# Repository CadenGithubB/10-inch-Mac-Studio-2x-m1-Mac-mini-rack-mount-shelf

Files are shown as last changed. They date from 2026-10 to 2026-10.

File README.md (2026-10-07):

# 10" rack cradle: Mac Studio + 2× Mac mini

A 5U, 3D-printable cradle for a 10-inch rack. It holds one Mac Studio standing on its side and two Mac minis standing on edge beside it. The minis sit between movable separators, so the same frame works with M1 minis now and M4 minis later.

There are two ways to build it:

- **One piece.** The whole frame is a single print on a 256 × 256 × 256 mm printer (Bambu X1/P1/A1 class). It needs no screws and no supports.
- **Bolt-together.** Five smaller parts fit a 235 mm bed and are joined with 10 M3 screws.

Both builds use the same separators.

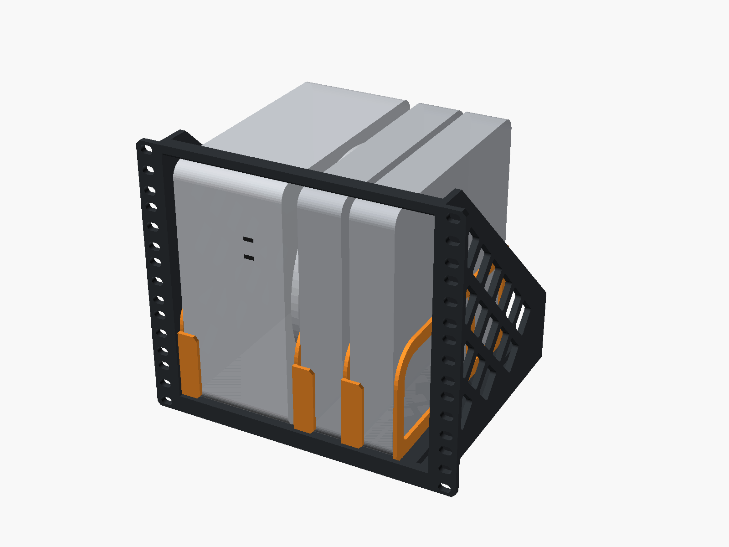
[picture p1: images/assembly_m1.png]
Mac Studio and two M1 minis in the cradle


| 2× M1 (now) | 2× M4 (later) | M1 + M4 |
|---|---|---|
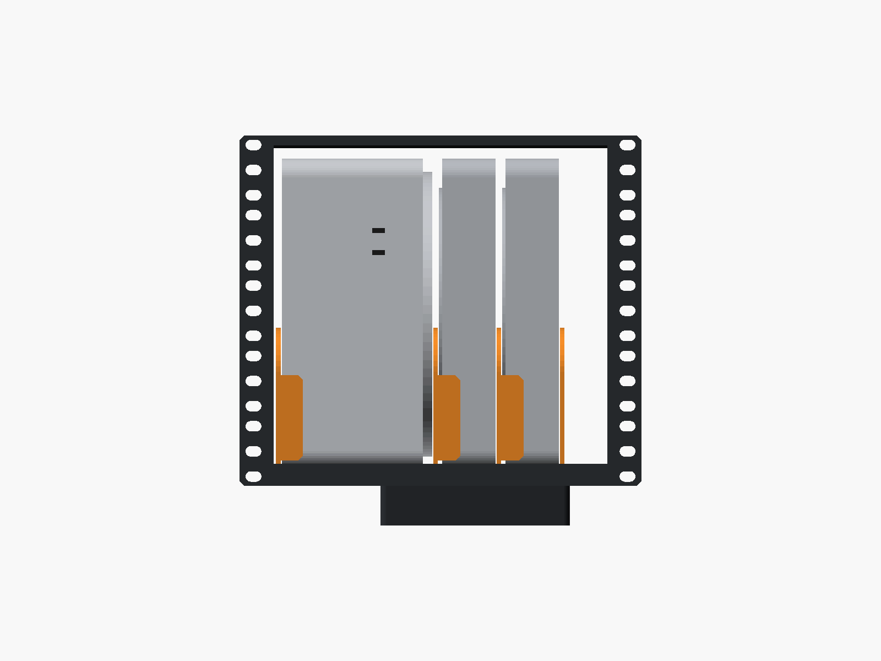
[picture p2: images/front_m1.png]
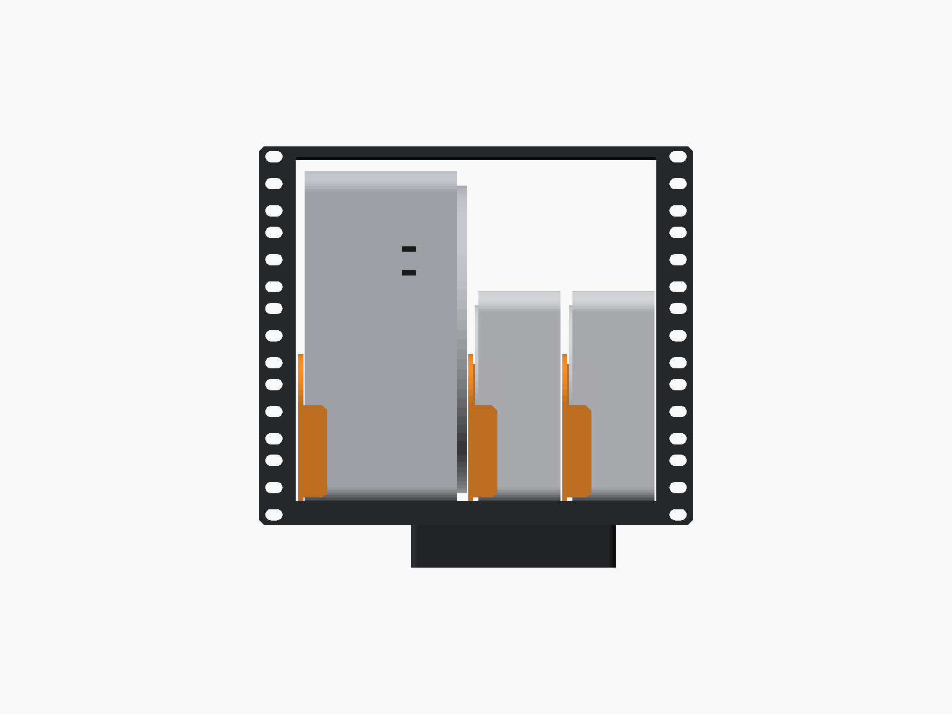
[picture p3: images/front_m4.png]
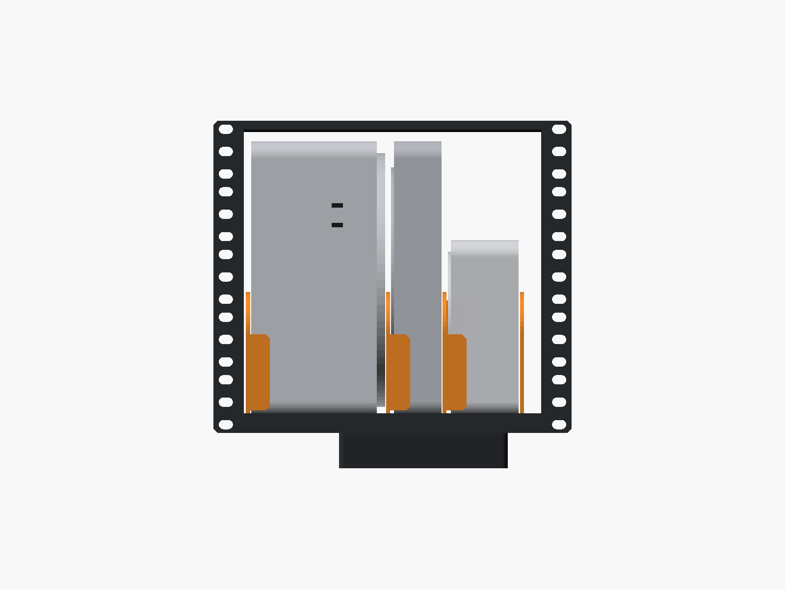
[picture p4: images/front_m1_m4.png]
|  |  |  |

## Why the Studio stands on its side

A 10" rack has 222.25 mm (8.75") between the rails. The Mac Studio and the M1 Mac mini are both 197 mm wide, so nothing fits beside a Studio lying flat.

On its side the Studio is 95 mm wide. That leaves about 110 mm next to it, which fits two minis on edge:

| Device | Footprint | On edge |
|---|---|---|
| Mac Studio | 197 × 197 × 95 mm | 95 mm wide, 197 mm tall |
| Mac mini M1 (2020) | 197 × 197 × 36 mm | 36 mm wide, 197 mm tall |
| Mac mini M4 (2024) | 127 × 127 × 50 mm | 50 mm wide, 127 mm tall |

The tallest device is 197 mm, so the cradle is 5U (222.25 mm).

The Studio's air intake is on its underside, so that face points **right**, toward the minis. Its foot holds the underside about 6 mm off the slot-2 separator. That leaves a gap down to the floor, right above the optional bottom fan (see below). Exhaust from all three Macs goes out the back, which is open. If you'd rather face the intake toward the open left side frame, set `studio_intake = "left"`. The bay is the same either way.

The floor between the two slot rows is a field of diamond vents, so air can rise into the bays from below. A solid band runs side to side across the middle of the vents. It stiffens the floor where it would otherwise sag most. The vents only help if the rack space under the cradle is open (an empty or vented U), not blocked by another device.

## Separators and doorstops

The floor has 6 separator slots. Count them from the left:

- **Slot 1** sits against the left side frame, on the Studio's left.
- **Slot 2** is the Studio's right-hand separator.
- **Slot 3** is where a separator goes after an M1.
- **Slot 4** is where a separator goes after an M4.
- **Slot 5** is where a separator goes after two M1s.
- **Slot 6** is where a separator goes after an M1 and an M4, in either order.

The slots go all the way through the 10 mm floor. Each separator drops 9.5 mm into one slot.

**Why only 6 slots:** the earlier version had a slot every 5 mm. That left walls only 1.6 mm thick between slots, held only at their ends and printed with the layer lines running across them. A firm sideways push on one separator (very roughly 4 kg) could crack one. With only the slots your layouts use, the thinnest wall is 11.6 mm. Strength grows with the square of thickness, so that's about 50× stronger, and the floor is much stiffer side to side. If you ever need other bay widths, set `slot_mode = "grid"` to get the 5 mm slots back. Treat those thin walls gently.

Every Mac has a separator on its left. Each separator has two **doorstops** on its right-hand side. They hook around the front and back edges of the Mac to their right, so that Mac can't slide out the front or back of the rack. They don't wrap all the way around.

- **Front doorstops** reach **14 mm** across the Mac's front. They cover only the edge closest to the separator, between 6 and 60 mm above the floor. The M4's front ports are in the middle of its 50 mm face, so they stay clear. With the Studio's underside facing right, its front ports end up on the right side of the face, away from its doorstop on the left. I couldn't measure exact port positions, so check against your Macs before printing.
- **Rear doorstops** reach 14 mm on the M4 separator. On the Studio/M1 separator they stay at **7 mm**, because the M1's rear ports run down the middle of its 36 mm back and an Ethernet or HDMI plug starts about 10 mm in. Change `rear_reach_studio_m1` if your plugs allow more.

The rear doorstop has to sit right behind the Mac it holds, and the separator after the last mini holds nothing. That gives three separator versions:

| File | Holds | Doorstops |
|---|---|---|
| [`stl/separator_studio_m1.stl`](stl/separator_studio_m1.stl) | the Studio or an M1 (197 mm deep) | front 14 mm; rear 7 mm at the back end |
| [`stl/separator_m4.stl`](stl/separator_m4.stl) | an M4 (127 mm deep) | front 14 mm; rear 14 mm, partway back and set high |
| [`stl/separator_end.stl`](stl/separator_end.stl) | nothing (it sits after the last mini) | none |

| Layout | Separators in slots | Bays (left → right) |
|---|---|---|
| Studio + 2× M1 | **1, 2, 3** Studio/M1, **5** end | Studio 96.4 · M1 37 · M1 37 · spare 27 mm |
| Studio + 2× M4 | **1** Studio/M1, **2, 4** M4 | Studio 96.4 · M4 52 · M4 52 mm (against the side frame) |
| Studio + M1 + M4 | **1, 2** Studio/M1, **3** M4, **6** end | Studio 96.4 · M1 37 · M4 52 · spare 12 mm |
| Studio + M4 + M1 | **1** Studio/M1, **2** M4, **4** Studio/M1, **6** end | Studio 96.4 · M4 52 · M1 37 · spare 12 mm |

Side-to-side play is 1.4 mm for the Studio, 1 mm for an M1 and 2 mm for an M4. Front-to-back play between the doorstops is 2.5 mm, which leaves room for ABS shrinking as it cools. For your M1 setup, print three Studio/M1 separators and one end separator. When you move to M4 minis, print two M4 separators.

The floor under the Studio has no slots, so it stays solid under the heaviest Mac. The spare bay in the M1 layout (about 27 mm) is wide enough for something thin, such as a USB hub or a slim SSD enclosure.

### Putting Macs in and taking them out

A separator can't slide past the Mac it holds, so you put Macs in from left to right:

1. Drop the slot-1 separator in.
2. Slide the Studio in about 1.5 cm to the right of its bay, then push it left so it tucks behind the doorstops.
3. Drop in the separator on the Studio's right.
4. Repeat for each mini.

To take Macs out, work from the right:

1. Lift out the separator on a Mac's right.
2. Slide the Mac about 1.5 cm right so it clears the doorstops on its left.
3. Pull the Mac out the front.

An M4 separator is easier, because its rear doorstop sits high: lift it about 85 mm, clear of the 127 mm-tall M4, and pull it out the front.

If you'd rather take any Mac out without touching the others, set `doorstop_rear = false` and re-export the separators. You then get front doorstops only. To remove a Mac, lift its left separator 10 mm, pull the separator out, then pull the Mac out. The 4 mm ramp at the back of the floor still stops a Mac from sliding off the back.

## Bottom fan (optional)

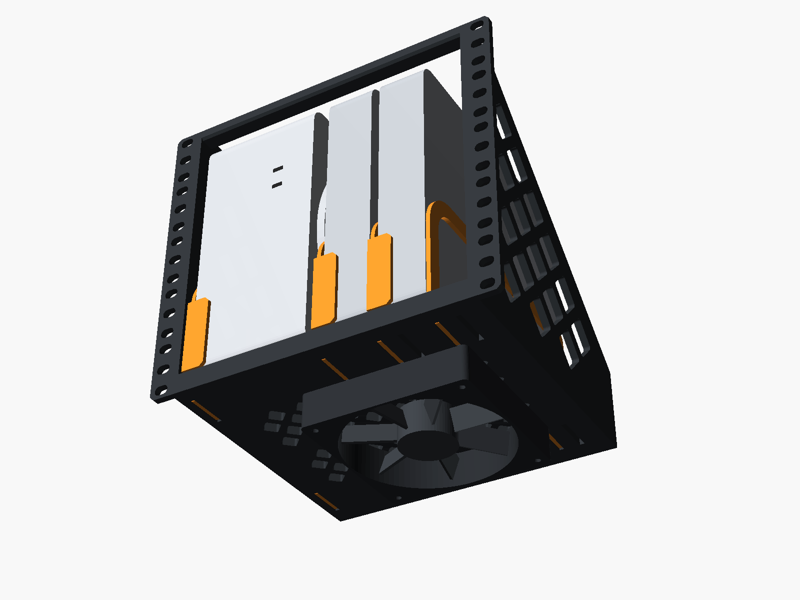
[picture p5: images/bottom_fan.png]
The cradle from below with a 120 mm fan


The floor has four countersunk holes for a standard **120 mm fan** (105 mm screw spacing). The fan mounts underneath and blows up through the floor vents. It's centred 25 mm right of the Studio's right-hand separator, so it sits mostly under the minis. The Studio's intake gap lies over the fan's blades rather than its dead center hub.

- **Hardware:** 4× M4 × 40 countersunk screws and 4× M4 nuts (nylon-insert nuts won't vibrate loose). They go down through the floor and the fan's corner holes. The heads sit flush with the floor. For a 15 mm slim fan, use M4 × 30. A standard 120 mm finger guard can go under the fan on the same screws.
- **Rack space:** the fan hangs 25 mm below the cradle, inside the 1U under it. Leave that U empty so the fan can pull air in.
- **Power:** a 5 V USB fan (for example a 5 V Noctua 120 mm) can run off a spare USB port on one of the Macs. A 12 V fan needs its own supply.
- **Where the air goes:** the Macs sit right on the floor, so they cover most of the vents under them. The air comes up through the gaps between them: the Studio's intake gap, the separator windows, and the space between the minis. Open floor where no Mac sits, such as the spare bay or behind the shorter M4s, is an easy escape route. If you want to push more air into the Macs, cover those vents with tape.

Set `fan_mount = false` to leave the holes out.

## Build A: one piece (256 mm printer)

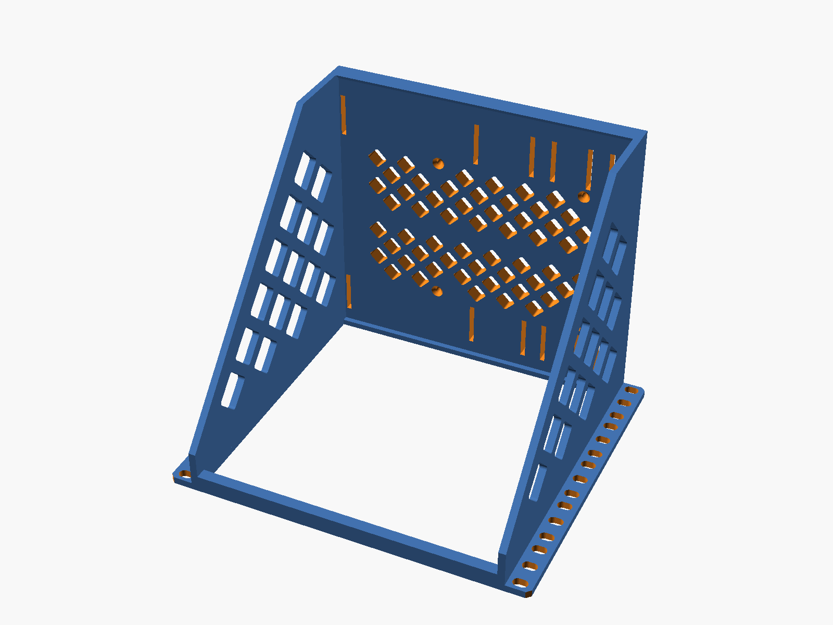
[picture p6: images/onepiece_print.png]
One-piece frame in print orientation


| File | Qty | Size (mm) |
|---|---|---|
| [`stl/frame_onepiece.stl`](stl/frame_onepiece.stl) | 1 | 254 × 221.5 × 206.5 |
| [`stl/separator_studio_m1.stl`](stl/separator_studio_m1.stl) | 3 for 2× M1 | 206 × 100 × 17 |
| [`stl/separator_m4.stl`](stl/separator_m4.stl) | 2 for 2× M4 (later) | 201 × 100 × 17 |
| [`stl/separator_end.stl`](stl/separator_end.stl) | 1 for 2× M1 | 198 × 100 × 3 |

The frame STL is already in print orientation: **face-down**, with the rack ears and the front edges on the bed. Printed this way:

- The top bar sits on the plate instead of bridging 210 mm in mid-air.
- The side-frame cutouts are 45° diamonds, and the rear stop is a 45° ramp.
- The floor vents are 45° diamonds as well.
- The widest bridge is 3.4 mm, at the tops of the separator slots.

It needs no supports.

The frame is 254 mm wide, which leaves about 1 mm on each side of a 256 mm plate. Center it, and don't add an outer brim. The part touches the bed only along a thin rectangular outline, so make sure the plate is clean. If you want more grip, use an inner-only brim or a little glue stick.

**Suggested settings:** 0.2 mm layers, 4 walls, 5 top/bottom layers, 15–20% gyroid infill. The frame is mostly thin walls, so walls add strength more than infill does. If you want more, go to 5–6 walls rather than 100% infill. The frame takes about 0.5 kg of filament. The separators print flat on their left face with the doorstops pointing up. They use 3 walls and need no supports.

**Material:** ABS, ASA or PETG. ABS and ASA hold their shape to about 95°C, compared with about 70°C for PETG. PLA can soften over time next to a warm Mac Studio.

**Printing in ABS or ASA:**

- Use an enclosed printer, such as an X1C or P1S, not an open A1. Let the chamber warm up for 10–15 minutes before starting, and keep the door closed.
- Set the bed to 100–110°C. Turn the part-cooling fan off for the first layers and keep it low (0–20%) after that.
- Stay at 15–20% infill. Solid ABS shrinks harder as it cools and is more likely to warp.
- The frame touches the bed along a thin outline, and its outer corners are the most likely to lift. Glue stick helps. There's no room for an outer brim on the left and right edges of a 256 mm plate, but an inner brim works. Give the separators a 3–5 mm brim.
- If the big frame keeps warping, the bolt-together version (Build B) prints as smaller, flatter parts that are much easier in ABS.
- Print somewhere ventilated, because ABS gives off fumes.

**Hardware:** only 4–6 rack screws, plus cage nuts if your rails need them. The ear slots are 6.6 × 10 mm, which fits M6, M5 and 10-32 screws and rail hole spacings from 235 to 237 mm. The optional bottom fan needs 4 M4 × 40 countersunk screws and nuts.

**Setup:**

1. Mount the frame in the rack with at least 2–3 screws per ear, including the top and bottom positions.
2. Load the separators and Macs left to right, as described under "Putting Macs in and taking them out". The Studio goes on its side with its underside facing right, toward the minis. Lift each Mac slightly to clear the 4 mm lip on the front edge. There is 6.4 mm of headroom under the top bar.

## Build B: bolt-together (235 mm bed)

| File | Qty | Size (mm) | Notes |
|---|---|---|---|
| [`stl/bolted/side_frame_left.stl`](stl/bolted/side_frame_left.stl) | 1 | 221 × 207 × 22 | Prints inner face down. The rack ear stands up. |
| [`stl/bolted/side_frame_right.stl`](stl/bolted/side_frame_right.stl) | 1 | 221 × 207 × 22 | Same as the left frame, mirrored. |
| [`stl/bolted/floor.stl`](stl/bolted/floor.stl) | 1 | 211 × 207 × 14 | Prints top face up. |
| [`stl/bolted/top_bar.stl`](stl/bolted/top_bar.stl) | 1 | 211 × 12 × 8 | Ties the frames together at the top front. |
| `stl/separator_*.stl` | per layout | up to 206 × 100 × 17 | Same separators as the one-piece build. |

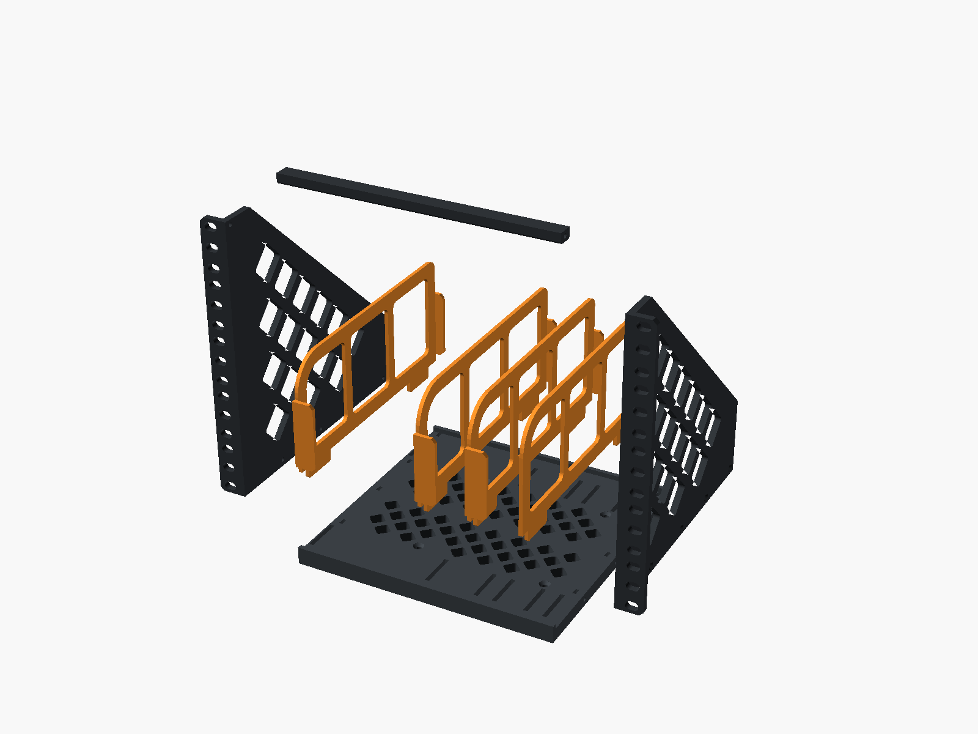
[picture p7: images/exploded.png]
Bolt-together parts


All parts are in print orientation and need no supports. The largest part is 222 × 211 mm. Any bed that is 235 × 235 mm or larger works. A 250 × 210 mm bed (Prusa MK4) also works if you turn the parts lengthwise.

**Suggested settings:** the same material and layer height as the one-piece build.

| Part | Walls | Infill |
|---|---|---|
| Side frames | 4 | 25% gyroid |
| Floor | 3 | 15–20% |
| Top bar | 4 | 40% |

**Hardware:**

- 10× M3 × 16 countersunk screws (DIN 7991 / ISO 10642)
- 10× M3 hex nuts
- 4–6 rack screws
- Optional bottom fan: 4× M4 × 40 countersunk screws and 4× M4 nuts

**Assembly:**

1. Drop an M3 nut into each of the 8 slots near the side edges of the floor. Slide one nut into each of the 2 slots in the back face of the top bar.
2. Hold a side frame against each side of the floor, with the ears at the front. Fasten each frame with 4 countersunk screws from the outside.
3. Fit the top bar between the top front corners of the frames, with one screw per side.
4. Then follow the setup steps for the one-piece build.

## Load

Everything hangs from the front rails: a Studio (2.7–3.6 kg) plus two M1 minis (1.2 kg each). The diamond lattice in each side frame carries that load back to the rack ears. If your rack has a shelf or a support point under the cradle, use it as well.

## Rack requirements

- 222.25 mm clear between the rails. The cradle body is 220.75 mm wide.
- About 207 mm of depth behind the front face of the ears, plus about 60 mm behind that for cables.
- 5U of vertical space.

## Customizing

Everything is in [`mac_rack_shelf.scad`](mac_rack_shelf.scad) (OpenSCAD 2021.01 or newer). Open it in OpenSCAD and use the Customizer, or set values on the command line. Useful parameters:

| Parameter | Default | What it does |
|---|---|---|
| `part` | `assembly` | What to render: `assembly`, `frame_onepiece`, `separator_studio_m1`, `separator_m4`, or a bolted part |
| `build` | `onepiece` | Frame used in the assembly preview: `onepiece` or `bolted` |
| `config` | `m1` | Preset used in the assembly preview: `m1`, `m4`, `m1_m4`, `m4_m1` |
| `rack_opening` | 222.25 | Clear width between your rack's rails |
| `rail_hole_pitch` | 236.5 | Centre-to-centre of the rail holes |
| `slot_w` / `tab_clear` | 3.4 / 0.3 | Separator fit. Raise `slot_w` if the tabs are too tight on your printer. |
| `floor_vents` | `true` | Diamond vents in the floor between the slot rows |
| `vent_spine` | 10 | Width of the solid band across the middle of the vents (0 removes it) |
| `slot_mode` | `presets` | `presets`: the 6 slots the layouts use. `grid`: a slot every 5 mm (thinner walls). |
| `doorstop_rear` | `true` | Set to `false` for front doorstops only, so any Mac slides out on its own |
| `doorstop_reach` | 14 | How far the front doorstops (and the M4 rear one) hook across a Mac |
| `fan_mount` | `true` | Screw holes for a 120 mm fan under the floor |
| `fan_offset_x` | 25 | Fan centre, in mm right of the Studio's right-hand separator |
| `studio_intake` | `right` | Which way the Studio's underside (air intake) faces |
| `rear_reach_studio_m1` | 7 | How far the Studio/M1 rear doorstop hooks across the back. It's kept short to clear the M1's rear plugs. |
| `studio_play` | 1.4 | Side-to-side play in the Studio bay. This also sets where slot 1 sits. |
| `vent_pitch` / `vent_strut` | 22 / 5 | Vent size and rib width |
| `sep_h` | 90 | Separator height above the floor |
| `studio_dim`, `m1_dim`, `m4_dim` | Apple specs | Device sizes used for the preview |

To regenerate the STLs and images, run `./build.sh`. On a headless machine, run `xvfb-run -a ./build.sh`.

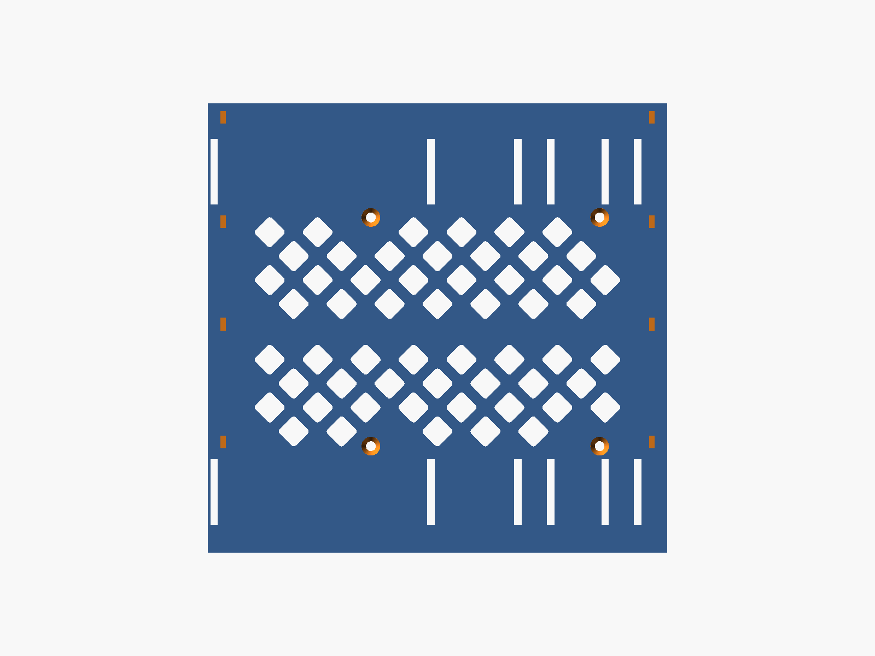
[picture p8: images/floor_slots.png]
Floor with separator slots and vents


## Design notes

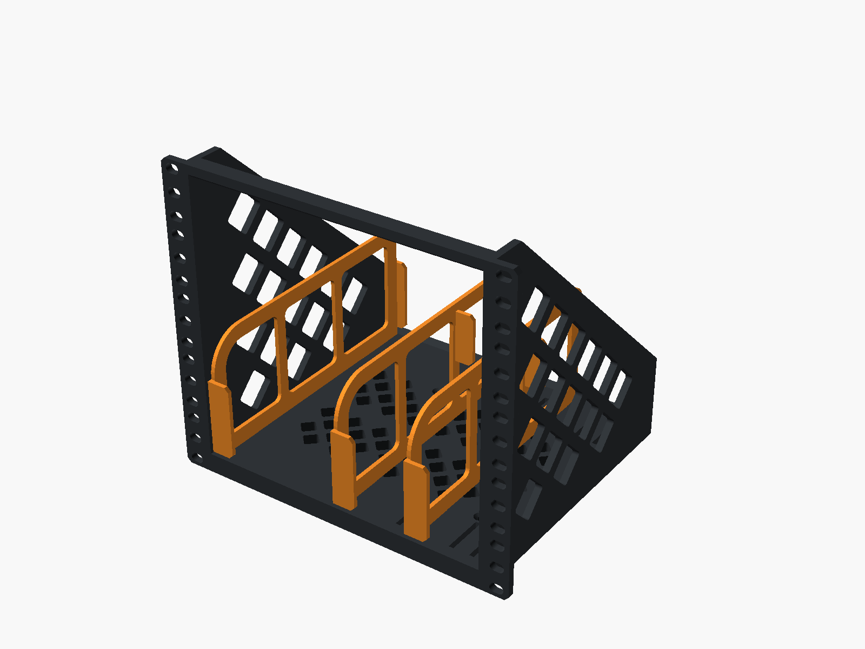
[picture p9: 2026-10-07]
images/separators_m4.png

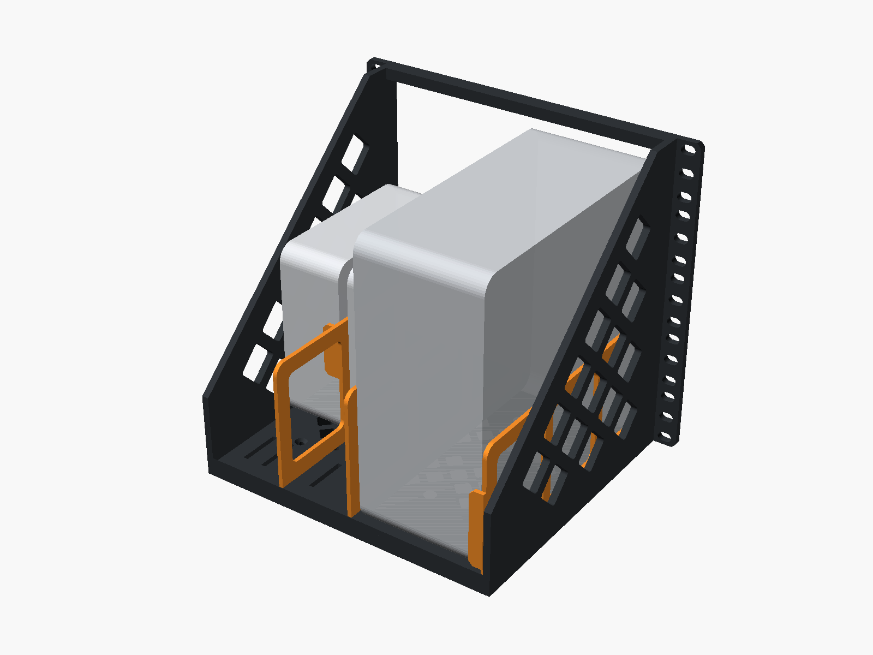
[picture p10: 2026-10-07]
images/rear_m4.png

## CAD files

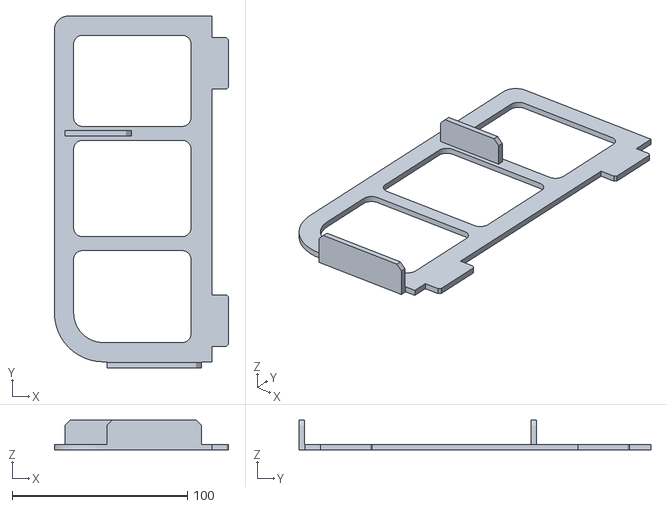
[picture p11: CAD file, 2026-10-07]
stl/separator_m4.stl
99.5 x 201.0 x 17.0

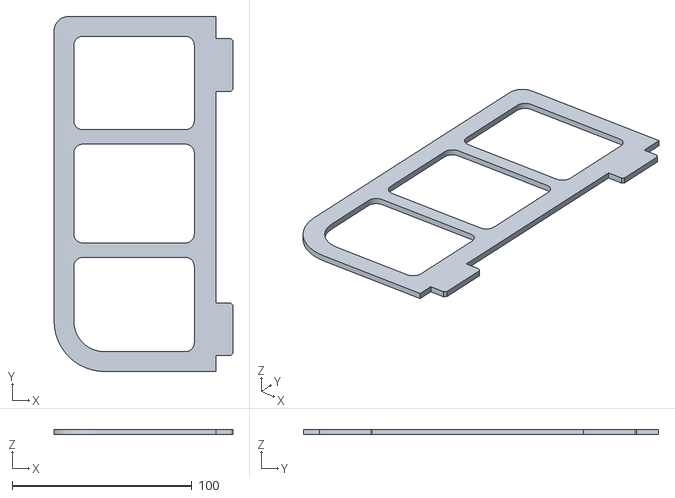
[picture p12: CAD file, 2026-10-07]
stl/separator_end.stl
99.5 x 197.5 x 3.00

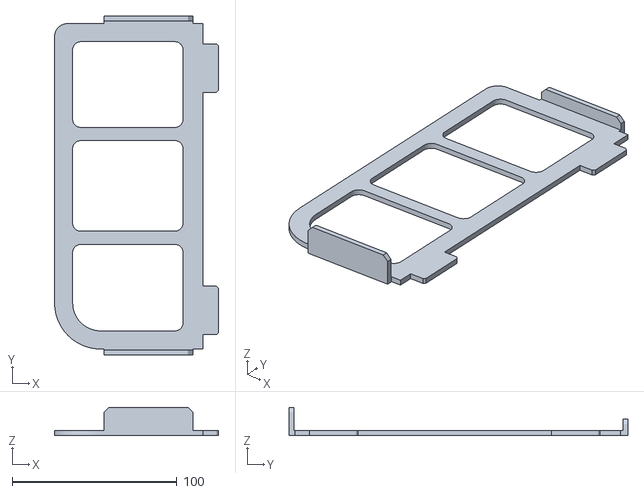
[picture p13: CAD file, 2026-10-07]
stl/separator_studio_m1.stl
99.5 x 205.5 x 17.0

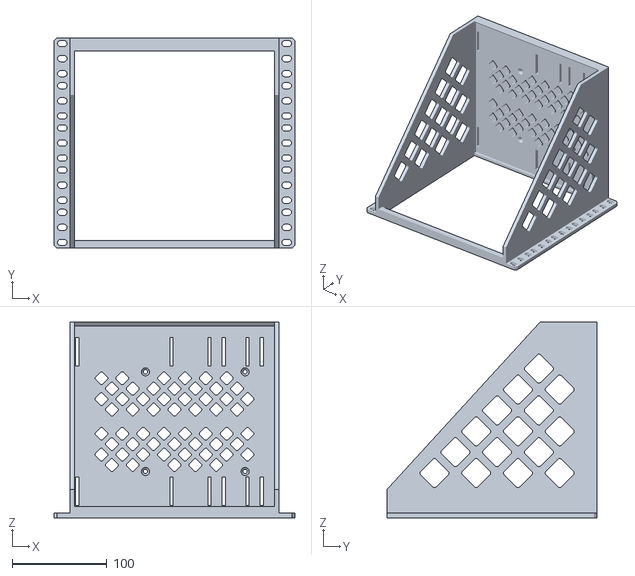
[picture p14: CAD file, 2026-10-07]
stl/frame_onepiece.stl
254.0 x 221.4 x 206.5

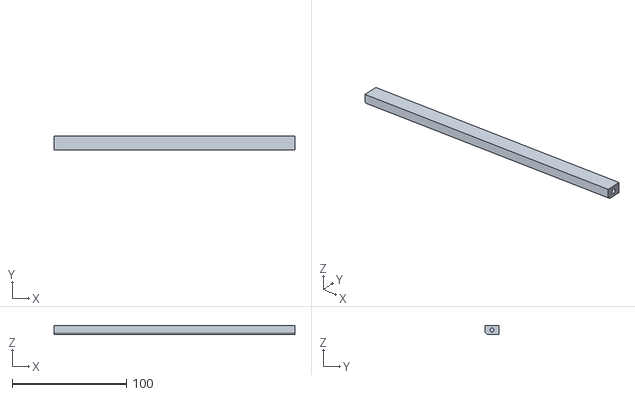
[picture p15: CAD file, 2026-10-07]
stl/top_bar.stl
210.8 x 12.0 x 8.00

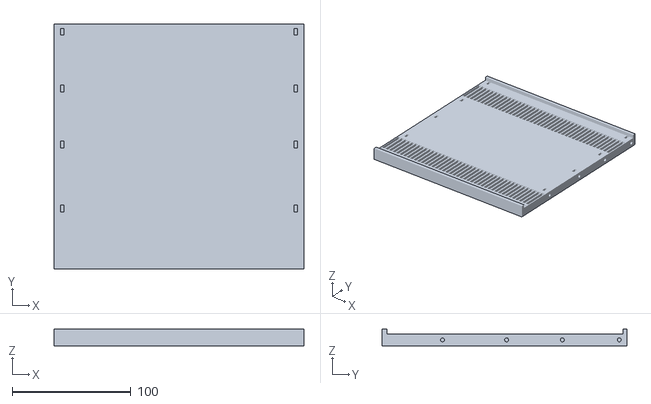
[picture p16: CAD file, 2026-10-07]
stl/floor.stl
210.8 x 206.5 x 14.0

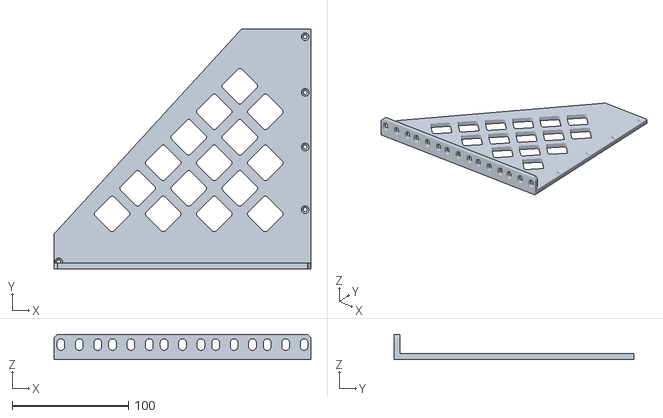
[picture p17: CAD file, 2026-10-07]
stl/bolted/side_frame_right.stl
221.4 x 206.5 x 21.6

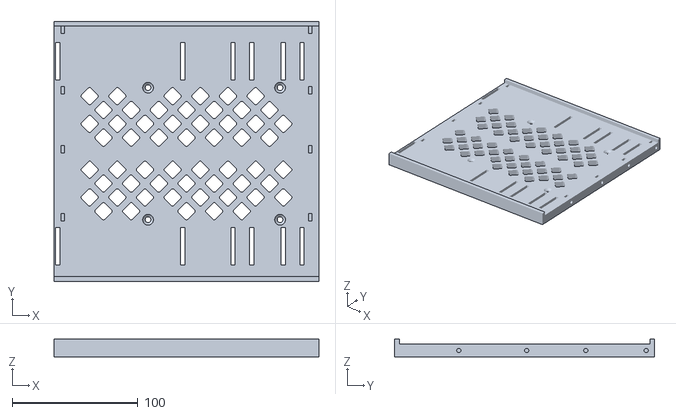
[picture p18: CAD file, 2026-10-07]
stl/bolted/floor.stl
210.8 x 206.5 x 14.0

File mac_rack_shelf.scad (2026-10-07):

// =====================================================================
//  10" rack cradle: 1x Mac Studio + 2x Mac mini (M1 now, M4 later)
//  5U, open front, 3D-printable. Two ways to build it:
//    * one piece  - the whole frame in a single print, face-down on a
//                   256 x 256 mm bed, no supports, no screws
//    * bolted     - five smaller parts joined with M3 screws (235 mm bed)
//
//  Layout (front view):
//
//      |<-------------- 210.75 mm between side plates -------------->|
//      | |  Mac Studio    | |  mini  | |  mini  | |   spare / gap    |
//      |S|  on its side   |S|        |S|        |S|                  |
//      | |  (96.4 mm bay) | |        | |        | |                  |
//      +=+================+=+========+=+========+=+==================+
//       1                 2        3   4     5    6     (separator slots)
//
//  Separators drop into numbered slots, so the same frame takes
//  M1 minis (36 mm thick), M4 minis (50 mm), or a mix. Every Mac has a
//  separator on its left, and each separator has small doorstops on its
//  right-hand side that hook around the front (and back) edge of that Mac.
//
//  Coordinates (assembled):  X = left/right (0 = rack centre),
//  Y = depth (0 = back face of the rack ears, + towards the rear),
//  Z = up (0 = bottom of the frame).
//
//  Render one part:   openscad -D 'part="frame_onepiece"' -o frame.stl mac_rack_shelf.scad
//  The floor can take an optional 120 mm fan underneath (fan_mount).
//
//  Parts: assembly | frame_onepiece | separator_studio_m1 | separator_m4 | separator_end
//         side_frame_left | side_frame_right | floor | top_bar   (bolted build)
// =====================================================================

/* [View] */
part   = "assembly";  // [assembly, frame_onepiece, separator_studio_m1, separator_m4, separator_end, side_frame_left, side_frame_right, floor, top_bar]
// Frame shown in the assembly preview
build  = "onepiece";  // [onepiece, bolted]
// Preset separator layout used by the assembly preview
config = "m1";        // [m1, m4, m1_m4, m4_m1, studio_only]
show_devices = true;
show_fan     = true;   // draw the optional bottom fan in the preview
explode = 0;          // [0:5:60] pulls the bolted parts apart

/* [Rack] */
U              = 44.45;
rack_units     = 5;
panel_w        = 254;     // 10" panel width
rack_opening   = 222.25;  // clear width between the rails (8.75")
rail_hole_pitch = 236.5;  // centre-to-centre of rail holes (racks vary 235-237)
side_clear     = 0.75;    // gap between side plate and rail, per side
ear_slot_d     = 6.6;     // fits M6 / M5 / 10-32 rack screws
ear_slot_len   = 10;      // horizontal slot, absorbs 235-237 mm hole pitch

/* [Devices] */
studio_dim = [197, 197, 95];   // W, D, H lying flat (Apple spec)
m1_dim     = [197, 197, 36];
m4_dim     = [127, 127, 50];

/* [Frame] */
side_t      = 5;     // side plate thickness
ear_t       = 5;     // rack ear thickness
depth       = 201.5; // frame depth behind the ears
h_rear      = 60;    // side-frame height at the rear
col_d       = 25;    // full-height solid column behind the ear
frame_border = 12;   // width of the outer frame members
bottom_band = 22;    // solid band along the floor joint
lat_pitch   = 44;    // diamond lattice: centre spacing
lat_strut   = 8;     // diamond lattice: strut width (45 deg, prints face-down or flat)
onepiece_overlap = 0.5;  // floor/top bar sink this far into the side plates

/* [Floor] */
floor_t     = 10;
lip_h       = 4;    // front lip that stops devices sliding out
lip_t       = 4;
rear_lip_h  = 4;
rear_lip_t  = 3.5;  // bolted floor only; the one-piece floor uses a 45 deg ramp

/* [Separator slots] */
// presets: only the 6 slots the M1/M4 layouts use (thick floor between them)
// grid:    a slot every slot_pitch mm, for odd-sized devices (1.6 mm walls between slots)
slot_mode   = "presets";   // [presets, grid]
slot_pitch  = 5;
slot_w      = 3.4;
m1_play     = 1;     // side-to-side play in an M1 bay (37 mm bay)
m4_play     = 2;     // side-to-side play in an M4 bay (52 mm bay)
slot_rows   = [[8, 38], [155, 185]];   // Y ranges of the two slot rows (cut through the floor)
studio_play = 1.4;   // side-to-side play in the Studio bay; sets where slot 2 sits
slot_wall   = 1.2;   // floor left between slot 1 and the left side plate

/* [Floor vents] */
floor_vents      = true;
vent_pitch       = 22;   // diamond centre spacing
vent_strut       = 5;    // rib width between diamonds (45 deg, prints without supports)
vent_side_margin = 16;   // solid floor kept along each side plate
vent_row_margin  = 5;    // solid floor kept next to each slot row
vent_spine       = 10;   // solid left-to-right band across the middle of the vents (0 = none)

/* [Separators] */
sep_t       = 3;
sep_h       = 90;    // height above the floor
tab_clear   = 0.3;   // per end, along Y
tab_depth   = 9.5;   // tabs reach 0.5 mm short of the floor's underside

/* [Doorstops] */
// Each separator holds the Mac on its right: a doorstop in front of it and
// one behind it. They print flat with the separator, pointing up. The
// separator after the last mini holds nothing and has no doorstops.
doorstop_reach = 14;         // how far the front doorstops (and the M4 rear one) reach across the Mac
rear_reach_studio_m1 = 7;    // Studio/M1 rear doorstop: kept short to clear the M1's rear plugs
doorstop_t     = 3;          // doorstop thickness, front to back
doorstop_z     = [16, 70];   // height of the front doorstop and the Studio/M1 rear one
m4_rear_z      = [56, 94];   // the M4 rear doorstop sits high so the separator lifts out over an M4
doorstop_rear  = true;       // false: front doorstops only, so any Mac slides out on its own
dev_front      = -1;         // front face of the Macs (back of the floor's front lip)
dev_play_y     = 2.5;        // front-to-back play between the doorstops (leaves room for ABS shrinking ~0.5%)

/* [Bottom fan] */
// Optional 120 mm fan screwed under the floor, blowing up through the vents.
// M4 countersunk bolts go down through the floor and the fan's corner holes,
// with nuts underneath; the heads sit flush with the floor.
fan_mount      = true;
fan_size       = 120;
fan_thick      = 25;     // preview only; a 25 mm fan fits in the 1U below the cradle
fan_hole_pitch = 105;    // standard 120 mm fan screw spacing
fan_hole_d     = 4.5;    // M4 clearance (fan corner holes are about 4.3-4.5 mm)
fan_csk_d      = 8.6;    // M4 countersunk head
fan_offset_x   = 25;     // fan centre, right of the Studio's right-hand separator
studio_intake  = "right"; // [right, left] which way the Studio's underside (its air intake) faces

/* [Top bar] */
bar_h       = 8;
bar_d       = 12;

/* [Hardware: M3 countersunk + hex nut] */
bolt_d      = 3.4;
csk_d       = 6.6;
nut_af      = 5.5;   // across flats
nut_t       = 2.4;
nut_clear   = 0.3;
floor_bolt_y = [46, 100, 147, 195];
floor_bolt_z = 5;
nut_inset   = 7;     // nut centre distance from the floor/bar end face

$fn = 48;
eps = 0.01;

// ---------------------------------------------------------------------
// Derived dimensions
// ---------------------------------------------------------------------
panel_h  = rack_units * U - 0.8;            // 221.45 for 5U
frame_w  = rack_opening - 2 * side_clear;   // outside of side plates
inner_w  = frame_w - 2 * side_t;            // between side plates
xi       = inner_w / 2;                      // inner face of right plate
xo       = frame_w / 2;                      // outer face of right plate
y_front  = -ear_t;
y_back   = depth;
bar_bolt_y = y_front + bar_d / 2;
bar_bolt_z = panel_h - bar_h / 2;

// Slot 1 sits against the left side plate, on the Studio's left. Slot 2 is
// the Studio's right-hand separator. The rest sit where a separator lands
// after one or two minis (M1 or M4), unless its doorstops would hit the
// right side plate. The floor under the Studio has no slots.
slot_x1 = -xi + slot_w / 2 + slot_wall;
slot_x0 = slot_x1 + sep_t + studio_dim[2] + studio_play;
fan_c   = [slot_x0 + fan_offset_x, (slot_rows[0][1] + slot_rows[1][0]) / 2];
fan_holes = [for (sx = [-1, 1], sy = [-1, 1]) fan_c + [sx, sy] * fan_hole_pitch / 2];

function bay_w(kind) = kind == "m4" ? m4_dim[2] + m4_play : m1_dim[2] + m1_play;
// a separator after the last mini has no doorstops, so it only needs to clear the side plate
function slot_fits(x) = x + sep_t / 2 + 0.5 <= xi;
// Separator positions from the Studio's right-hand separator onward, for a
// list of minis left to right. The last one is left out when the final
// mini simply sits against the side plate.
function mini_xs(devs, i = 0, x = slot_x0) =
    i < len(devs)
        ? concat([x], mini_xs(devs, i + 1, x + sep_t + bay_w(devs[i])))
        : (slot_fits(x) ? [x] : []);
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

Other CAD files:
stl/bolted/side_frame_left.stl
stl/bolted/top_bar.stl

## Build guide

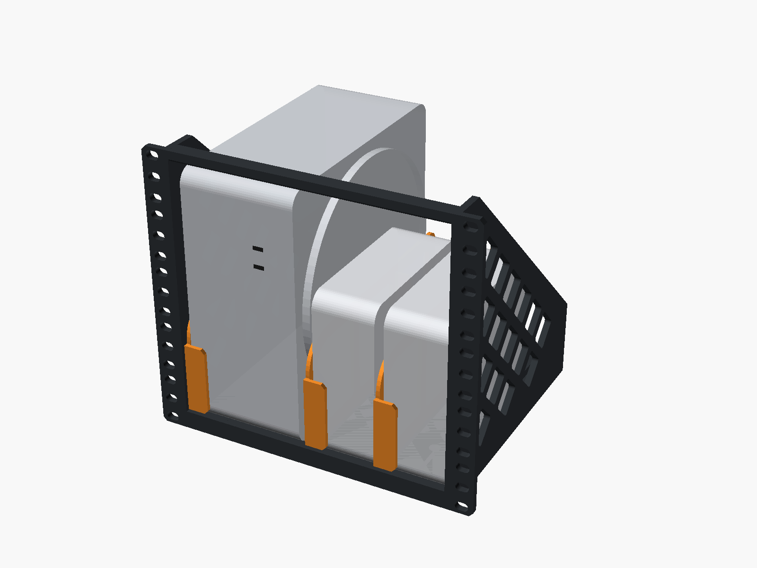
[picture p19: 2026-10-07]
images/assembly_m4.png

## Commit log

2026-10-07 Add 5U 10" rack cradle for Mac Studio + 2 Mac minis
    Parametric OpenSCAD model of a bolt-together, 3D-printable cradle:
    the Mac Studio stands on its side, and two Mac minis stand on edge in
    bays set by drop-in separators. The floor has 42 numbered slots at a
    5 mm pitch, so the same frame takes M1 minis (36 mm) now and M4 minis
    (50 mm) later.
    Includes print-oriented STLs, preview renders, a build script and a
    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
    [floor.stl, mac_rack_shelf.scad, separator.stl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]
2026-10-07 Add one-piece frame that prints face-down on a 256 mm bed
    The side frames, floor and top bar can now be fused into a single
    part (frame_onepiece) with no screws. It prints face-down, with the
    rack ears on the bed, inside 254 x 221.5 x 206.5 mm. In that
    orientation the top bar sits on the plate instead of bridging 210 mm.
    To keep it support-free, the side-frame cutouts are now a 45 degree
    diamond lattice (whole diamonds only, so no flat ceilings), and the
    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
    [floor.stl, frame_onepiece.stl, mac_rack_shelf.scad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]
2026-10-07 Cut separator slots through the floor and add floor vents
    The separator slots now go all the way through the 10 mm floor, and
    the separator tabs are 9.5 mm deep (up from 4.7 mm), so each separator
    sits about twice as deep and stands up more firmly.
    The floor between the two slot rows gets a field of 45 degree diamond
    vents so air can rise into the bays from below. Solid margins stay
    along the side plates and next to each slot row. Because every vent
    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
    [floor.stl, frame_onepiece.stl, mac_rack_shelf.scad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]
2026-10-07 Halve the separator slots and add a solid band across the vents
    Separator slots now exist only beside the Studio: 23 slots at a 5 mm
    pitch, renumbered so slot 1 is always the Studio's separator. Taking
    every other slot instead would have left the M4 bays at 47 or 57 mm.
    Dropping the slots under the Studio keeps every layout exact and
    leaves the floor solid under the heaviest Mac. The mirrored layout
    with the Studio on the right is no longer supported.
    New presets: 2x M1 = 1, 9, 17; 2x M4 = 1, 12, 23; M1 + M4 = 1, 9, 20;
    M4 + M1 = 1, 12, 20.
    The floor vents are split into two fields by a solid band that runs
    from side plate to side plate across the middle (vent_spine, 10 mm).
    It stiffens th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
    [floor.stl, frame_onepiece.stl, mac_rack_shelf.scad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]
2026-10-07 Add a slot left of the Studio and doorstops on the separators
    A new slot 1 sits against the left side plate, so the Studio now has a
    separator on both sides. Everything to its right moves over 4.4 mm.
    Slots are now 1-21: slot 2 is the Studio's right-hand separator, and
    slots 2-21 run 5 mm apart.
    Every Mac now has a separator on its left. That separator carries two
    doorstops on its right face, which hook 7 mm around the Mac's front and
    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
    [floor.stl, frame_onepiece.stl, mac_rack_shelf.scad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]
2026-10-07 Cut only the six slots the layouts use and drop the slot numbers
    The 5 mm slot grid left walls only 1.6 mm thick between slots. Those
    walls were held only at their ends (the slots go through the floor) and
    loaded across their layer lines in the face-down print. A firm sideways
    push on one separator could crack one, and the two slot rows made the
    floor weak side to side.
    By default the floor now has only the separator positions the M1/M4
    layouts use. They are computed from the bay widths: left of the Studio,
    right of the Studio, after one M1, after one M4, after two M1s, and
    after an M1 plus an M4. The thinnest wall between slots goes from
    1.6 mm to 11.6 mm. slot_mode = "grid" brings back a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
    [floor.stl, frame_onepiece.stl, mac_rack_shelf.scad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]
2026-10-07 Double the front doorstops and add an end separator
    The front doorstops now reach 14 mm across each Mac (was 7 mm), and so
    does the M4 separator's rear doorstop. The Studio/M1 rear doorstop stays
    at 7 mm (rear_reach_studio_m1): the M1's rear ports run down the middle
    of its 36 mm back, and a longer stop could foul an Ethernet or HDMI plug.
    With 14 mm doorstops, a separator in slot 6 would hit the side plate.
    That separator holds nothing anyway, so the separator after the last
    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
    [floor.stl, frame_onepiece.stl, mac_rack_shelf.scad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]
2026-10-07 Add a 120 mm fan mount under the floor and turn the Studio's intake inward
    The floor gets four countersunk M4 holes on the standard 105 mm
    pattern for a 120 mm fan that mounts underneath and blows up through
    the vents. Vents near the screws are skipped, so the floor stays solid
    around each hole. The fan is centred 25 mm right of the Studio's
    right-hand separator (fan_offset_x), so it sits mostly under the minis
    with the Studio's intake gap over its blades. fan_mount = false leaves
    the holes out.
    The Studio now faces its underside (air intake) right, toward the
    minis (studio_intake = "right"). Its foot leaves a 6 mm gap beside the
    slot-2 separator, open down to the floor above the fan. This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
    [floor.stl, frame_onepiece.stl, mac_rack_shelf.scad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]
2026-10-07 Widen doorstop play for ABS and add ABS print settings
    ABS shrinks about 0.5% as it cools, which would close the 1 mm of
    front-to-back play between a separator's doorstops around a 197 mm Mac.
    dev_play_y goes from 1 mm to 2.5 mm. Only the separators change; the
    frame's fits already have room.
    The README now covers infill and walls (walls over infill; 100% is not
    needed), lists ABS/ASA as materials, and gives ABS notes: enclosure,
    bed and fan settings, brim limits on a 256 mm plate, and the
    bolt-together fallback if the one-piece frame warps.
    Claude-Session: https://claude.ai/code/session_0164yidGLDerjWgRfBmfACgW
    [mac_rack_shelf.scad, separator_end.stl, separator_m4.stl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]
